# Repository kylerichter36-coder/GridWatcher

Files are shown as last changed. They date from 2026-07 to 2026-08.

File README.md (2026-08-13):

# GridWatcher






> **A ~R1,500 dual-device LoRa sensor + Raspberry Pi-class server system that predicts power outages before they happen, texts your phone, and retrains its own ML model automatically.**

---

## Why I Built This
Living with an unreliable local power grid meant sudden blackouts, lost work, and voltage sags damaging household electronics. Commercial utility monitors are either expensive proprietary hardware or reactive meters that only alert *after* the power is already out. GridWatcher was built to provide localized, real-time AC voltage and frequency telemetry with early-warning machine learning risk predictions and instant SMS notifications.

---

## System Architecture & Data Flow

```mermaid
graph LR
    subgraph Edge Hardware
        ZMPT[ZMPT101B AC Sensor] -->|ADC / GPIO2| ESP32[ESP32-C6 Base Station]
        ESP32 -->|Layer 1 C++ Rules| L1[Instant State: Normal/Sag/Surge/Blackout]
        ESP32 -->|Layer 2 C++ ML Engine| L2[Predictive Risk Score 0-100%]
    end

    subgraph Long-Range Telemetry
        ESP32 -->|12-Byte LoRa Packet| Handheld[ESP32-C6 Handheld Dashboard]
        ESP32 -->|12-Byte LoRa Packet| Pi[Orange Pi / Armbian Server]
    end

    subgraph Home Automation & ML Pipeline
        Pi -->|MQTT| HA[Home Assistant Dashboard]
        Pi -->|CSV Logger| Trainer[Windows Retraining GUI]
        Trainer -->|Train Random Forest| Header[Export C++ grid_model.h]
        Trainer -->|Auto-OTA Binaries| ESP32
        Pi -->|Termux ADB Bridge| SMS[Instant SMS Alerts]
    end
```

---

## System Categorization

### Implemented in V1
* **True RMS AC Sampling**: ZMPT101B RMS voltage sampling and zero-crossing frequency detection on GPIO 2.
* **Layer 1 State Machine**: Real-time deterministic C++ grid state classification (`BLACKOUT`, `SURGE`, `BROWNOUT_SAG`, `FREQ_JITTER`, `NORMAL`).
* **12-Byte Binary LoRa Protocol**: Compact binary packet structure (`GridPacket`) with magic header verification (`0x4757`).
* **Handheld TFT Dashboard**: ESP32-C6 handheld receiver with ST7789 240x135 display rendering live electrical, battery, and signal status.
* **Android Termux Gateway & SMS Bridge**: Refurbished Android phone running Termux/ADB to log cellular tower telemetry, host live status web endpoints, and dispatch instant SMS outage alerts via `termux-sms-send`.
* **Home Assistant Integration**: Real-time MQTT telemetry reporting and Lovelace dashboard integration.
* **1-Click Windows Setup**: Standalone `install_startup.bat` script that configures `arduino-cli`, ESP32 cores, and required libraries.

### Experimental Features (V1)
* **Layer 2 ML Risk Engine**: Random Forest ensemble (`grid_model.h`) evaluating 8 model inputs to compute continuous 0–30s pre-outage risk scores.
* **Pure Timestamp Feature Extraction**: Pure timestamp-based search (`timestamp_ms`) computing 10s and 30s rolling rates of change and variance.
* **Dual-Stage Wireless Auto-OTA**: Wi-Fi self-flashing engine checking local server (`192.168.3.47:5000`) with direct GitHub HTTPS fallback.

### Planned for V2 (Future Revision)
* **Custom Integrated PCB**: Monolithic PCB design replacing devboards and point-to-point wiring.
* **Precision AC Front-End**: Dedicated high-voltage metering IC with factory calibration against laboratory reference meters.
* **Feature Importance & Model Interpretability**: Extract and log Gini feature importance (and SHAP values) from the trained Random Forest to confirm whether `cell_signal` contributes meaningfully or is redundant relative to AC-derived features.
* **Cryptographic Packet Security**: Hardware-accelerated AES-128 payload encryption and packet signing.
* **Dedicated Hardware Watchdog**: External timer IC for emergency hardware reset during power dips.

---

<details>
<summary><b>Click to expand Deep Technical Specifications & Architecture</b></summary>

### Repository Structure

```
GridWatcher/
├── home_sender/              # ESP32-C6 Base Station transmitter firmware
│   ├── home_sender.ino       # ZMPT101B RMS sampling, Layer 1 status, 12-byte LoRa TX
│   └── grid_model.h          # Exported C++ Random Forest decision tree model
├── gridwatcher_dashboard2/   # ESP32 Handheld receiver & TFT dashboard firmware
│   └── gridwatcher_dashboard2.ino
├── windows_trainer/          # Automated Windows training pipeline & GUI
│   ├── gridwatcher_ml_gui.py # PyQt GUI, gap-aware feature extractor, C++ exporter
│   └── install_startup.bat   # 1-click dependency installer (arduino-cli standalone)
├── WORKING_ON/               # Active development status & phase documentation
│   └── README.md
└── version.json              # Current firmware & ML model version manifest
```

### Prototype Bill of Materials & Cost Breakdown (ZAR)

| Unit | Key Components | Prototype Cost (incl 15% VAT) |
|---|---|:---:|
| **Handheld Receiver Dashboard** | ESP32-C6, SX1262 LoRa, ST7789 TFT Display, 2000mAh LiPo, 868MHz High-Gain Antenna, Protoboard | **R736** |
| **Base Station Sender** | ESP32-C6, SX1262 LoRa, ZMPT101B AC Sensor, Hi-Link 5V Power, Boost Regulator, 868MHz High-Gain Antenna, LiPo Backup | **R843** |
| **Central Home Server & Gateway** | Armbian/Orange Pi Server + Refurbished Android Phone (Termux) | Reused / R0 |
| **Total Combined Prototype Build** | Both complete units including antennas, cabling, and hardware | **~R1,580** |

### Core Technical Design

#### Design Philosophy
GridWatcher combines direct AC power delivery measurements with auxiliary environmental side-channel indicators to predict electrical grid instability.

#### 1. Dual-Layer Classification Architecture

* **Layer 1: Deterministic C++ State Machine (`home_sender.ino`)**
  Evaluates instantaneous voltage and frequency using strict severity precedence:
  1. **Blackout**: `V < 180.0V` or `F < 45.00Hz`
  2. **Voltage Surge**: `V > 250.0V`
  3. **Brownout Sag**: `180.0V <= V < 210.0V`
  4. **Frequency Jitter**: `210.0V <= V <= 250.0V` and (`F < 49.50Hz` or `F > 50.50Hz`)
  5. **Normal**: `210.0V <= V <= 250.0V` and `49.50Hz <= F <= 50.50Hz`

* **Layer 2: Experimental Time-Series ML Risk Model (`grid_model.h`)**
  Evaluates **8 total inputs** to compute continuous 0–30s pre-outage risk scores:

  ##### Feature Rationale & Engineering Hypotheses

  | Feature | Category | Rationale & Mechanics |
  |---|---|---|
  | `voltage` | Direct AC | Instantaneous RMS AC voltage (V); physically tracks supply level. |
  | `frequency` | Direct AC | Instantaneous line frequency (Hz); reflects utility generation/load balance. |
  | `dV_dt_10s` | Direct AC | 10-second voltage rate of change ($\text{V}/\text{s}$); detects rapid dips or surges. |
  | `dF_dt_10s` | Direct AC | 10-second frequency rate of change ($\text{Hz}/\text{s}$); catches sudden frequency decay. |
  | `v_std_30s` | Direct AC | 30-second voltage standard deviation; quantifies short-term AC amplitude instability. |
  | `f_std_30s` | Direct AC | 30-second frequency standard deviation; measures line frequency turbulence. |
  | `v_slope_30s` | Direct AC | 30-second linear regression voltage slope ($\text{V}/\text{s}$); captures multi-second voltage trend directional drift. |
  | `cell_signal` | Environmental | Cellular network tower signal strength (RSRP in dBm, clamped to -120 to 0 dBm). |

  * **Cellular RSRP Feature Rationale**:
    > **Engineering Hypothesis**: Cell towers sharing the regional utility feeder may show supply degradation or backup-power failover during severe grid stress, providing a secondary spatial/regional indicator alongside direct AC metrics. Expected to be a lagging signal (tower backup typically buffers 4–8 hours) rather than instantaneous, unlike the AC-derived features.

  Outputs an experimental risk score from 0.0% to 100.0% using an ensemble of 3 Random Forest decision trees (`max_depth=4`) exported directly into native C++ functions (`tree0()`, `tree1()`, `tree2()`).

#### 2. 12-Byte Binary LoRa Telemetry Protocol

Telemetry is packed into a 12-byte binary structure (`GridPacket`), providing an **approximately 2.8x reduction in payload data size** compared to the legacy 34-byte ASCII string payload ($34 / 12 \approx 2.83\times$):

```cpp
struct __attribute__((packed)) GridPacket {
    uint16_t magic = 0x4757;  // 2 Bytes: 'GW' Sync Header
    int16_t  voltage_x10;     // 2 Bytes: Scaled Voltage (e.g. 2301 = 230.1V)
    uint16_t freq_x100;       // 2 Bytes: Scaled Frequency (e.g. 5000 = 50.00Hz)
    uint8_t  status;          // 1 Byte: GridStatus Enum (0..4)
    uint8_t  risk_score;      // 1 Byte: Experimental Risk % (0..100)
    uint8_t  ml_version;      // 1 Byte: Model Version (ML_MODEL_VERSION)
    int8_t   rssi;            // 1 Byte: Cellular Tower Signal Strength RSRP (-120..0 dBm)
    uint8_t  base_battery;    // 1 Byte: Base Station Battery % (0..100)
    int8_t   phone_battery;   // 1 Byte: Phone Hotspot Battery % (-1 or 0..100)
};
// Total Size: 12 Bytes
```

Both Handheld and Server receivers validate `packet.magic == 0x4757` to verify packet structure and reject malformed or unrelated RF data.

### Machine Learning Pipeline & Training

1. Telemetry datasets are logged automatically by the Orange Pi server (~10s log interval).
2. `gridwatcher_ml_gui.py` loads `telemetry.csv` and computes rolling features with timestamp gap invalidation ($\Delta t > 35.0\text{s}$).
3. Samples are labeled with a continuous 0–30s forward-looking horizon (`target_risk = 1` if an anomaly occurs within the upcoming 30 seconds while current state is Normal).
4. Scikit-Learn performs a **chronological 80/20 train/test holdout split** on historical telemetry, fitting a 3-tree Random Forest classifier (**86.48% training accuracy / 82.75% test holdout accuracy** for live model **v31**) and exporting decision rules into `home_sender/grid_model.h`. *Note: Accuracy is an experimental metric evaluated on historical local dataset logs and does not serve as a guarantee of real-world outage prediction capability.*
5. The Base Station firmware is compiled using `arduino-cli` and updated wirelessly via local HTTP OTA or direct GitHub HTTPS fallback.

### Current Prototype Limitations

1. **Prototype Hardware Measurement**: The ZMPT101B analog sensing module and ESP32 ADC chain are prototype-grade components and have not been calibrated against laboratory-grade reference meters.
2. **Experimental ML Validation**: The machine learning model is trained on telemetry from a single installation site. Real-world outage prediction accuracy requires extensive multi-site dataset validation across diverse grid topologies.
3. **OTA Network Scope & Security**: While local network OTA endpoints (`/update`, `/trigger-ota`) operate unauthenticated within a trusted LAN boundary, the direct GitHub fallback path fetches firmware binaries over the public internet using `setInsecure()` TLS without certificate pin verification.
4. **Known Limitations of the Cellular RSRP Feature**:
   * **Single-Tower Dependency**: Telemetry currently observes a single cell tower's backup behavior rather than a true regional signal until multiple gateway locations are logging.
   * **Site & Carrier Variation**: Tower backup behavior varies significantly by carrier and site (battery-only vs. generator-backed), causing RSRP proxy reliability to be inconsistent across network sectors.
   * **Feature Importance Unvalidated**: RSRP has not yet been quantitatively validated against Gini/SHAP feature importance metrics to confirm whether the trained model actively relies on this feature during real anomaly events vs. riding along with AC voltage features.

</details>

---

## Local Setup & Installation

Sensitive credentials are excluded from source control via `.gitignore`:
* **Wi-Fi Credentials**: Loaded via `home_sender/secrets.h` (`#if __has_include("secrets.h")`) or hardware NVS storage.
* **AP & OTA Passwords**: Defined as configurable macros (`#ifndef AP_PASSWORD`, `#ifndef OTA_PASSWORD`) overridable via `secrets.h`.
* **Server Credentials**: `gridwatcher_ml_gui.py` checks environment variable `GRIDWATCHER_PI_PASS` or local `secrets.json` before falling back to dev defaults.

To set up a new machine:
1. Run `windows_trainer/install_startup.bat` to install `arduino-cli`, the ESP32 board core, required libraries (`RadioLib`, `Adafruit GFX`, `ST7789`, `BusIO`), and Python dependencies.
2. Launch `windows_trainer/gridwatcher_ml_gui.py` to run retraining and automated OTA deployment.

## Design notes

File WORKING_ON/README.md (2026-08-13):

# Active Development & Work In Progress

This directory tracks active development status, system verification, and the engineering roadmap for the GridWatcher project.

---

## Current Status: GridWatcher V1 (Functional Prototype)

### Completed V1 Accomplishments

1. **Dual-Layer Anomaly & Predictive Risk Engine**
   - **Layer 1 (Deterministic Rules)**: Implemented C++ threshold state machine in `home_sender.ino` (`BLACKOUT`, `SURGE`, `BROWNOUT_SAG`, `FREQ_JITTER`, `NORMAL`) using strict evaluation precedence.
   - **Layer 2 (Experimental ML Risk Model)**: Implemented Random Forest model (`grid_model.h`) operating on 8 total inputs (voltage, frequency, cell signal, `dV/dt_10s`, `dF_dt_10s`, `v_std_30s`, `f_std_30s`, `v_slope_30s`).
   - **Pure Timestamp Search**: Implemented pure timestamp-based search (`timestamp_ms`) in `computeRollingFeatures()` for 10s and 30s rate of change and regression slope.

2. **12-Byte Binary LoRa Protocol Migration**
   - Migrated from legacy ASCII string transmission (`V:230.1,F:50.0...`) to a 12-byte binary packed struct (`GridPacket`).
   - Achieved an **approximately 2.8x reduction in payload data size** ($34 / 12 \approx 2.83\times$, ~8ms transmission duration), complying with EU868 and US915 duty-cycle budgets.
   - Validates `0x4757` magic sync header in receiver firmware to verify packet structure and reject malformed/unrelated RF data.

3. **Machine Learning Pipeline & Evaluation**
   - Implemented continuous 0–30s forward-looking target labeling in `gridwatcher_ml_gui.py` for early-warning outage risk classification.
   - Chronological 80/20 train/test holdout split evaluating **86.48% Train Accuracy / 82.75% Test Holdout Accuracy** (`v31`).
   - Automated Scikit-Learn tree export directly into C++ conditional logic (`tree0`, `tree1`, `tree2`).

4. **Multi-Machine Deployment & Security Refinements**
   - Configurable AP/OTA passwords (`AP_PASSWORD`, `OTA_PASSWORD`) and environment/json server credentials (`GRIDWATCHER_PI_PASS` / `secrets.json`).
   - Android Termux cellular gateway and SMS bridge (`phone_server/live_cell_bridge.py`) capturing cell tower RSRP telemetry and sending instant SMS alerts via `termux-sms-send`.
   - Updated `install_startup.bat` to automatically download standalone `arduino-cli` and required Arduino libraries (`RadioLib`, `Adafruit GFX`, `Adafruit ST7789`, `Adafruit BusIO`).
   - Direct dual-stage Auto-OTA engine checking local server (`192.168.3.47:5000`) with direct GitHub HTTPS fallback.

---

## Task Verification & Component Matrix

| Component | Status | Verification Summary |
|---|---|---|
| `home_sender.ino` | Completed | Pure timestamp-based search, 30-sample ring buffer, Layer 1 state machine, Layer 2 RF integration, 12-byte binary LoRa TX. |
| `grid_model.h` | Completed | 3-tree Random Forest C++ export with 8 model inputs (`v31`). |
| `gridwatcher_dashboard2.ino` | Completed | Binary struct unpacking (12 bytes), configurable OTA password, and magic header `0x4757` verification. |
| `gridwatcher_ml_gui.py` | Completed | Gap-aware feature extraction ($\Delta t > 35s$), chronological 80/20 train/test holdout evaluation, 1-click single-binary OTA pipeline. |
| `install_startup.bat` | Completed | Standalone `arduino-cli` download, ESP32 core install, library dependency resolution. |

---

## Roadmap: Planned for V2 (Custom PCB Revision)

* **Monolithic PCB Hardware**: Replace prototype breadboard wiring with a custom 2-layer PCB.
* **Calibrated High-Voltage AC Metering**: Integrate dedicated metering IC (e.g. ADE7753 / ATM90E26) calibrated against laboratory-grade reference meters.
* **Cryptographic Security**: Hardware AES-128 payload encryption and HMAC packet signing.
* **Enclosure & Power Supply**: Custom 3D-printed DIN-rail enclosure with integrated UPS battery backup.

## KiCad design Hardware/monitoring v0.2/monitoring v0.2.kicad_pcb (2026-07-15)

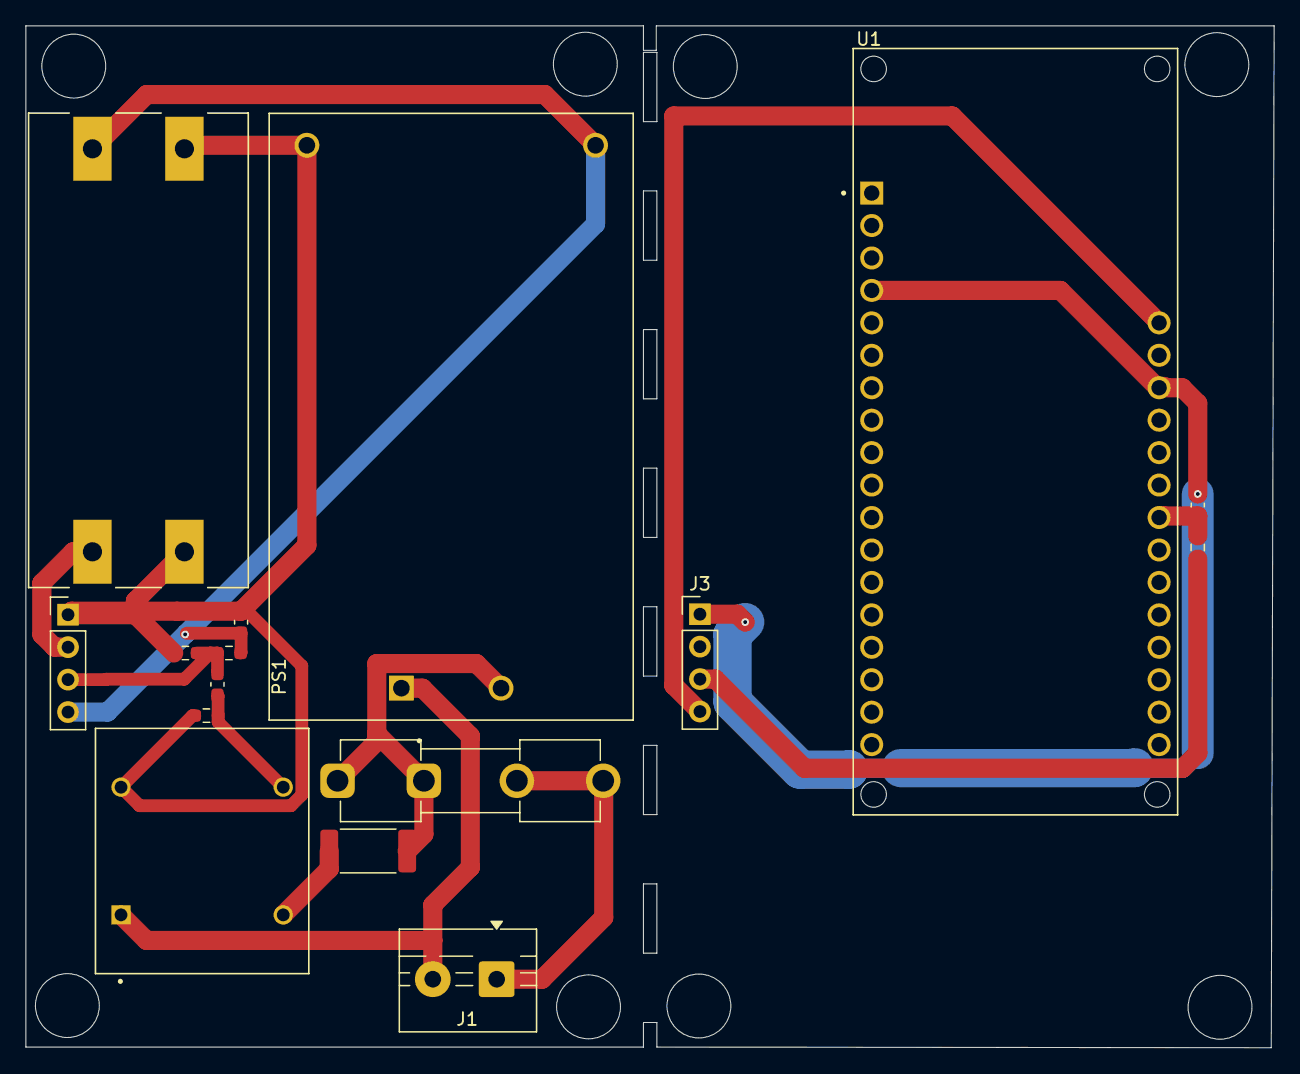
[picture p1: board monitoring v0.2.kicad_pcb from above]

Board: 2 copper layers, 97.7 x 80.0 mm, 16 parts (0 on the bottom side), 11 nets.

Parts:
C1: 1uF; C_0603_1608Metric_Pad1.08x0.95mm_HandSolder
C2: 0.1uF; C_0603_1608Metric_Pad1.08x0.95mm_HandSolder
C3: 10nF; C_0603_1608Metric_Pad1.08x0.95mm_HandSolder
F1: 1A; Fuseholder_Clip-5x20mm_Eaton_1A5601-01_Inline_P20.80x6.76mm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
J1: ST01x02; TerminalBlock_MaiXu_MX126-5.0-02P_1x02_P5.00mm
J2, J3: Conn_01x04_Pin; PinHeader_1x04_P2.54mm_Vertical
PS1: HLK-10M05; CONV_HLK-10M05
R1: 820K; R_2512_6332Metric_Pad1.40x3.35mm_HandSolder
R2: |2k; R_0603_1608Metric_Pad0.98x0.95mm_HandSolder
R3: 10k; R_0603_1608Metric_Pad0.98x0.95mm_HandSolder
R4: 5.1K; R_0603_1608Metric_Pad0.98x0.95mm_HandSolder
R5: 100; R_0603_1608Metric_Pad0.98x0.95mm_HandSolder
T1: ZMPT101B; XFMR_ZMPT101B
U1: DFR0654; MODULE_DFR0654
U2: MT3608_DC-DC_STEP_UP_CONVERTER_2A_BOOSTER_MODULE; MODULE_MT3608_DC-DC_STEP_UP_CONVERTER_2A_BOOSTER_MODULE

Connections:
3.3V: U1.2 (3.3V), U1.31 (3.3V)
/2v-28v: J2.2, U2.VOUT_P (VOUT+)
/5v: C2.2, J2.4, J3.4, PS1.4 (+VO), R3.2, U1.32 (VCC), U2.VIN_P (VIN+)
/L: F1.2, J1.1
/N: J1.2, PS1.1 (AC1), T1.1
/ZMPT101B: C1.2, J2.3, J3.3, R3.1, R4.2, R5.2
GND: C2.1, C3.2, J2.1, J3.1, PS1.3 (-VO), R2.1, R4.1, T1.4, U1.4 (GND), U1.30 (GND), U2.VIN_N (VIN-), U2.VOUT_N (VOUT-)
unnamed: C1.1, R2.2, T1.3
unnamed: F1.1, PS1.2 (AC2), R1.1
unnamed: R1.2, T1.2
unnamed: C3.1, R5.1, U1.26 (A3)

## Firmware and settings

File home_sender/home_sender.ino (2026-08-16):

/*
  GridWatcher: Base Station (Transmitter) — v3 Legal + Optimized
  Hardware: FireBeetle 2 ESP32-C6, SX1262 LoRa, MT3608 Step-up

  Compliance & Fixes:
  - TX interval 2000ms (was 1000ms) — EU/SA 868MHz 1% duty cycle compliance
  - TX power reduced to +14dBm (was +22dBm) — lowers battery draw & stays legal
  - Cell signal staleness timeout: 30s before marking as -999
  - Reinit backoff: doubles wait time on each failed reinit (max 80s)
  - Boot delay reduced to 500ms
  - Serial verbose mode flag (set false to suppress per-packet spam)
  - Battery: 5-sample average for stable reading
  - snprintf payloads — zero heap allocation

  LoRa Packet Format:
  V:<voltage>,F:<freq>,B:<base_batt>,S:<cell_dbm>,PB:<phone_batt>,SEQ:<seq>
*/

#include <Arduino.h>
#include <SPI.h>
#include <WiFi.h>
#include <WiFiClientSecure.h>
#include <HTTPClient.h>
#include <WebServer.h>
#include <Update.h>
#include <ESPmDNS.h>
#include <LittleFS.h>
#include <RadioLib.h>
#include <Preferences.h>
#include "grid_model.h"

#define CURRENT_VERSION ML_MODEL_VERSION
const char* OTA_VERSION_URL      = "http://192.168.3.47:5000/api/firmware/version.json";
const char* OTA_BIN_URL          = "http://192.168.3.47:5000/api/firmware/home_sender.bin";
const char* OTA_HANDHELD_BIN_URL = "http://192.168.3.47:5000/api/firmware/handheld.bin";

#ifndef LED_BUILTIN
  #define LED_BUILTIN 8
#endif
#define LED_PIN LED_BUILTIN

bool handheldUpdateReady = false;   // handheld.bin uploaded and waiting

void blinkDebugLED(int count) {
  for (int i = 0; i < count; i++) {
    digitalWrite(LED_PIN, HIGH);
    delay(100);
    digitalWrite(LED_PIN, LOW);
    delay(100);
  }
}

// GitHub Direct HTTP/HTTPS Auto-OTA Self-Flashing Engine (Local Server + GitHub Fallback)
void checkGitHubAutoOTA() {
  if (WiFi.status() != WL_CONNECTED) return;
  Serial.printf("[Auto-OTA] Checking for firmware updates (Local Version: v%d)...\n", CURRENT_VERSION);
  
  int remoteVersion = 0;
  String binUrl = "";
  String handheldUrl = "";

  // 1. Try Orange Pi local server first
  WiFiClient client;
  HTTPClient http;
  if (http.begin(client, OTA_VERSION_URL)) {
    int httpCode = http.GET();
    if (httpCode == HTTP_CODE_OK) {
      String payload = http.getString();
      int idx = payload.indexOf("\"version\":");
      if (idx != -1) {
        remoteVersion = payload.substring(idx + 10).toInt();
        binUrl = OTA_BIN_URL;
        handheldUrl = OTA_HANDHELD_BIN_URL;
      }
    }
    http.end();
  }

  // 2. Fall back to GitHub HTTPS if local server is unreachable
  if (remoteVersion == 0) {
    WiFiClientSecure secureClient;
    secureClient.setInsecure(); // Direct raw HTTPS fetch without root cert chain check
    if (http.begin(secureClient, "https://raw.githubusercontent.com/kylerichter36-coder/GridWatcher/main/version.json")) {
      int httpCode = http.GET();
      if (httpCode == HTTP_CODE_OK) {
        String payload = http.getString();
        int idx = payload.indexOf("\"version\":");
        if (idx != -1) {
          remoteVersion = payload.substring(idx + 10).toInt();
          binUrl = "https://raw.githubusercontent.com/kylerichter36-coder/GridWatcher/main/home_sender.bin";
          handheldUrl = "https://raw.githubusercontent.com/kylerichter36-coder/GridWatcher/main/handheld.bin";
        }
      }
      http.end();
    }
  }

  if (remoteVersion == 0) {
    Serial.println("[Auto-OTA] Could not check remote version from local server or GitHub.");
    return;
  }

  Serial.printf("[Auto-OTA] Version Check -> Local: v%d | Remote: v%d\n", CURRENT_VERSION, remoteVersion);

  if (remoteVersion <= CURRENT_VERSION) {
    Serial.printf("[Auto-OTA] Device is up to date (v%d >= v%d). No update required.\n", CURRENT_VERSION, remoteVersion);
    return;
  }

  // 3. Remote version is newer — download and flash home_sender.bin
  Serial.printf("[Auto-OTA] NEW FIRMWARE AVAILABLE! Upgrading v%d -> v%d...\n", CURRENT_VERSION, remoteVersion);
  Serial.printf("[Auto-OTA] Downloading binary from %s...\n", binUrl.c_str());

  bool isHttps = binUrl.startsWith("https");
  HTTPClient otaHttp;
  int httpCode = -1;

  if (isHttps) {
    WiFiClientSecure secClient;
    secClient.setInsecure();
    if (otaHttp.begin(secClient, binUrl)) {
      httpCode = otaHttp.GET();
    }
  } else {
    WiFiClient netClient;
    if (otaHttp.begin(netClient, binUrl)) {
      httpCode = otaHttp.GET();
    }
  }

  if (httpCode != HTTP_CODE_OK) {
    Serial.printf("[Auto-OTA] ERROR: Failed to download firmware binary (HTTP Code: %d). Aborting update.\n", httpCode);
    otaHttp.end();
    return;
  }

  int contentLength = otaHttp.getSize();
  if (contentLength < 100000) {
    Serial.printf("[Auto-OTA] ERROR: Firmware binary too small or invalid size (%d bytes). Aborting update.\n", contentLength);
    otaHttp.end();
    return;
  }

  Serial.printf("[Auto-OTA] Binary size: %d bytes. Flashing OTA update partition...\n", contentLength);

  if (!Update.begin(contentLength)) {
    Serial.printf("[Auto-OTA] ERROR: Update.begin(%d) failed! Code: ", contentLength);
    Update.printError(Serial);
    otaHttp.end();
    return;
  }

  WiFiClient* stream = otaHttp.getStreamPtr();
  size_t written = Update.writeStream(*stream);
  otaHttp.end();

  if (written != (size_t)contentLength) {
    Serial.printf("[Auto-OTA] ERROR: Wrote %d / %d bytes. Update incomplete!\n", (int)written, contentLength);
    Update.end(false);
    return;
  }

  if (!Update.end(true)) {
    Serial.print("[Auto-OTA] ERROR: Update.end() failed: ");
    Update.printError(Serial);
    return;
  }

  if (Update.hasError()) {
    Serial.print("[Auto-OTA] ERROR: Flashing encountered errors: ");
    Update.printError(Serial);
    return;
  }

  Serial.printf("[Auto-OTA] SUCCESS: Firmware v%d successfully flashed! Rebooting in 1s...\n", remoteVersion);
  delay(1000);
  ESP.restart();
}

// ==============================================================================
// [0] CONFIG FLAGS
// ==============================================================================
#define SERIAL_VERBOSE    true    // Set false to suppress per-packet TX log spam
#define TX_INTERVAL_MS    2000
#define TX_POWER_DBM      9    // +5 dBi antenna: 9dBm TX + 5dBi - 1dB loss = ~13dBm EIRP = ~12mW ERP
                               // Legal limit is 25mW ERP. Change to 22 ONLY if using a simple wire/0dBi antenna.
#define CELL_STALE_MS     30000

// LoRa radio config — MUST match exactly on sender and handheld
#define LORA_FREQ     868.0
#define LORA_BW       125.0
#define LORA_SF       10
#define LORA_CR       7
#define LORA_SYNC     0x12
#define LORA_PREAMBLE 8

// OTA Hub state — tracks which devices still need to update
bool bridgeUpdateReady    = false;   // bridge.py uploaded and waiting
bool senderUpdatePending  = false;   // sender own firmware staged, waiting for others
bool handheldConfirmed    = false;   // handheld reported OK
bool bridgeConfirmed      = false;   // phone bridge reported OK

// Grid State
float lastVoltage         = 0.0;
float lastFrequency       = 0.0;
float zmptCalibration     = 0.46;  // Multiplier mapping raw RMS ADC units to real AC Volts (adjust via /calibrate?val=0.46)
#define PIN_BOOT_BTN      9
#define PIN_ZMPT          6        // ZMPT101B active module analog OUT on GPIO 6

// Sender hub dashboard — upload firmware for all 3 devices from one page.
// Laptop accesses this at http://gridwatcher-sender.local/ota (stays on home WiFi).
const char HUB_HTML[] PROGMEM = R"rawliteral(
<!DOCTYPE html><html><head><meta charset='UTF-8'>
<title>GridWatcher OTA Hub</title>
<meta http-equiv='refresh' content='5'>
<style>
body{font-family:sans-serif;background:#0d1117;color:#e6edf3;margin:0;padding:20px;}
h1{color:#58a6ff;border-bottom:1px solid #30363d;padding-bottom:10px;}
.card{background:#161b22;border:1px solid #30363d;border-radius:8px;padding:16px;margin:12px 0;}
.card h3{margin-top:0;color:#79c0ff;}
.status{display:inline-block;padding:3px 10px;border-radius:12px;font-size:0.85em;font-weight:bold;}
.ok{background:#1a4731;color:#3fb950;}
.wait{background:#3d2b00;color:#e3b341;}
.ready{background:#1f3d6e;color:#58a6ff;}
input[type=file]{background:#21262d;color:#e6edf3;border:1px solid #30363d;padding:6px;border-radius:4px;width:100%;margin:8px 0;}
btn,input[type=submit]{padding:8px 16px;background:#238636;color:#fff;border:none;border-radius:6px;cursor:pointer;font-weight:bold;margin-top:6px;}
btn:hover,input[type=submit]:hover{background:#2ea043;}
.info{color:#8b949e;font-size:0.85em;margin-top:4px;}
table{width:100%;border-collapse:collapse;}
td,th{padding:8px 12px;border:1px solid #30363d;text-align:left;}
th{background:#21262d;color:#79c0ff;}
</style></head><body>
<h1>GridWatcher OTA Hub</h1>
<div class='card'>
<h3>Device Status</h3>
<table><tr><th>Device</th><th>Update Ready</th><th>Confirmed</th></tr>
<tr><td>Handheld</td>
    <td><span class='status %HREADY%'>%HREADYTXT%</span></td>
    <td><span class='status %HCONF%'>%HCONFTXT%</span></td></tr>
<tr><td>Phone Bridge</td>
    <td><span class='status %BREADY%'>%BREADYTXT%</span></td>
    <td><span class='status %BCONF%'>%BCONFTXT%</span></td></tr>
<tr><td>Sender (self)</td>
    <td><span class='status %SREADY%'>%SREADYTXT%</span></td>
    <td><span class='status ok'>%SCONFTXT%</span></td></tr>
</table>
</div>
<div class='card'>
<h3>1. Upload Handheld Firmware</h3>
<p class='info'>handheld will pull this automatically when you hold BOOT for 3s</p>
<form method='POST' action='/upload-handheld' enctype='multipart/form-data'>
<input type='file' name='file' accept='.bin'>
<input type='submit' value='Upload Handheld Firmware'>
</form>
</div>
<div class='card'>
<h3>2. Upload Bridge Script</h3>
<p class='info'>phone bridge checks for this on every startup</p>
<form method='POST' action='/upload-bridge' enctype='multipart/form-data'>
<input type='file' name='file' accept='.py'>
<input type='submit' value='Upload Bridge Script'>
</form>
</div>
<div class='card'>
<h3>3. Upload Sender Firmware (applied last)</h3>
<p class='info'>sender stages this and reboots automatically after handheld + phone confirm</p>
<form method='POST' action='/update' enctype='multipart/form-data'>
<input type='file' name='update' accept='.bin'>
<input type='submit' value='Stage Sender Firmware'>
</form>
</div>
</body></html>)rawliteral";

// ==============================================================================
// [1] HARDWARE & PIN DEFINITIONS
// ==============================================================================
#define LORA_CS   14
#define LORA_DIO1 4
#define LORA_RST  1
#define LORA_BUSY 5
#define PIN_BAT   0

// Onboard LED for visual TX feedback (no terminal needed)
// FireBeetle 2 ESP32-C6: try LED_BUILTIN first; change to your board's LED pin if needed
#ifndef LED_BUILTIN
  #define LED_BUILTIN 8
#endif
#define LED_PIN LED_BUILTIN
#define LED_TX_MS   30    // Short blip on successful TX
#define LED_ERR_MS  120   // Longer pulse on TX fail
unsigned long ledOffMs = 0;  // millis() when LED should turn off (0 = already off)

// ==============================================================================
// secrets.h is only present on the home PC that originally flashed this device.
// On other PCs (e.g. for ML retraining), it won't exist — that is fine because
// the compiled binary gets OTA-flashed FROM the Orange Pi which has the correct
// binary already. The #if __has_include guard prevents compile errors.
#if __has_include("secrets.h")
  #include "secrets.h"
#endif

// ---- Home WiFi (primary) ----
#ifdef SECRET_WIFI_SSID
const char* homeSSID = SECRET_WIFI_SSID;
const char* homePass = SECRET_WIFI_PASS;
#else
// No secrets.h on this PC — credentials are already stored in NVS from original flash
const char* homeSSID = "";
const char* homePass = "";
#endif

// ---- Phone hotspot (fallback when away from home) ----
const char* phoneSSID = "YOUR_PHONE_HOTSPOT_NAME";     // <-- fill in
const char* phonePass = "YOUR_PHONE_HOTSPOT_PASSWORD"; // <-- fill in

// ---- Sender AP (always on, for local debugging) ----
#ifndef AP_PASSWORD
  #define AP_PASSWORD "gridwatcher123"
#endif
const char* apSSID   = "GridWatcher-AP";
const char* apPass   = AP_PASSWORD;

// mDNS hostname — access OTA at http://gridwatcher-sender.local/update from any
// device on the same network. No WiFi switching needed on laptop.
#define MDNS_HOSTNAME "gridwatcher-sender"

WebServer server(80);

// ==============================================================================
// [3] GLOBALS, PACKET STRUCT & FEATURE CALCULATOR
// ==============================================================================
struct __attribute__((packed)) GridPacket {
    uint16_t magic = 0x4757;  // 2 Bytes: 'GW' Sync Header
    int16_t  voltage_x10;     // 2 Bytes: e.g. 2301 = 230.1V
    uint16_t freq_x100;       // 2 Bytes: e.g. 5000 = 50.00Hz
    uint8_t  status;          // 1 Byte: GridStatus Enum (0..4)
    uint8_t  risk_score;      // 1 Byte: Predictive Risk % (0..100)
    uint8_t  ml_version;      // 1 Byte: Model Version
    int8_t   rssi;            // 1 Byte: Cell Signal dBm
    uint8_t  base_battery;    // 1 Byte: Base Station Battery % (0..100)
    int8_t   phone_battery;   // 1 Byte: Phone Hotspot Battery % (-1 or 0..100)
};

struct TelemetrySample {
    float voltage;
    float frequency;
    unsigned long timestamp_ms;
};

#define RING_BUF_SIZE 30
TelemetrySample ringBuf[RING_BUF_SIZE];
int ringHead = 0;
int sampleCount = 0;

void addTelemetrySample(float v, float f, unsigned long ts) {
    ringBuf[ringHead] = {v, f, ts};
    ringHead = (ringHead + 1) % RING_BUF_SIZE;
    if (sampleCount < RING_BUF_SIZE) sampleCount++;
}

bool isRingBufferWarmedUp() {
    if (sampleCount < 2) return false;
    int idxOldest = (ringHead - sampleCount + RING_BUF_SIZE) % RING_BUF_SIZE;
    int idxNow    = (ringHead - 1 + RING_BUF_SIZE) % RING_BUF_SIZE;
    unsigned long elapsed = ringBuf[idxNow].timestamp_ms - ringBuf[idxOldest].timestamp_ms;
    return (elapsed >= 25000); // Warmed up when at least 25-30 real seconds of continuous telemetry are in buffer
}

// Layer 1: Strict Evaluation Precedence State Machine
GridStatus classifyGridStatus(float voltage, float frequency) {
    // 1. BLACKOUT (Highest Severity)
    if (voltage < 180.0f || frequency < 45.00f) {
        return GRID_STATUS_BLACKOUT;
    }
    // 2. SURGE
    if (voltage > 250.0f) {
        return GRID_STATUS_SURGE;
    }
    // 3. BROWNOUT SAG
    if (voltage >= 180.0f && voltage < 210.0f) {
        return GRID_STATUS_BROWNOUT_SAG;
    }
    // 4. FREQUENCY JITTER (Voltage normal 210V-250V, but frequency outside 49.5-50.5Hz)
    if (voltage >= 210.0f && voltage <= 250.0f && (frequency < 49.50f || frequency > 50.50f)) {
        return GRID_STATUS_FREQ_JITTER;
    }
    // 5. NORMAL (Lowest Severity)
    return GRID_STATUS_NORMAL;
}

void computeRollingFeatures(float &dV_dt_10s, float &dF_dt_10s, float &v_std_30s, float &f_std_30s, float &v_slope_30s) {
    if (!isRingBufferWarmedUp()) {
        dV_dt_10s = 0.0f; dF_dt_10s = 0.0f; v_std_30s = 0.0f; f_std_30s = 0.0f; v_slope_30s = 0.0f;
        return;
    }

    int idxNow = (ringHead - 1 + RING_BUF_SIZE) % RING_BUF_SIZE;
    unsigned long nowTs = ringBuf[idxNow].timestamp_ms;

    // 1. Pure timestamp-based search for sample closest to 10 seconds ago (10,000 ms)
    int idx10s = idxNow;
    float bestDiff10s = 999999.0f;
    for (int i = 1; i < sampleCount; i++) {
        int idx = (ringHead - 1 - i + RING_BUF_SIZE) % RING_BUF_SIZE;
        unsigned long elapsedMs = nowTs - ringBuf[idx].timestamp_ms;
        float diff = abs((float)elapsedMs - 10000.0f);
        if (diff < bestDiff10s) {
            bestDiff10s = diff;
            idx10s = idx;
        }
        if (elapsedMs > 15000) break; // Don't search past 15s
    }

    float dt10 = (nowTs - ringBuf[idx10s].timestamp_ms) / 1000.0f;
    if (dt10 < 1.0f) dt10 = 10.0f; // Safety fallback

    dV_dt_10s = (ringBuf[idxNow].voltage - ringBuf[idx10s].voltage) / dt10;
    dF_dt_10s = (ringBuf[idxNow].frequency - ringBuf[idx10s].frequency) / dt10;

    // 2. Pure timestamp-based collection for samples within the last 30 seconds (30,000 ms)
    int samplesIn30s = 0;
    int indices30s[RING_BUF_SIZE];
    for (int i = 0; i < sampleCount; i++) {
        int idx = (ringHead - 1 - i + RING_BUF_SIZE) % RING_BUF_SIZE;
        unsigned long elapsedMs = nowTs - ringBuf[idx].timestamp_ms;
        if (elapsedMs <= 30000) {
            indices30s[samplesIn30s++] = idx;
        } else {
            break;
        }
    }

    if (samplesIn30s < 2) {
        v_std_30s = 0.0f; f_std_30s = 0.0f; v_slope_30s = 0.0f;
        return;
    }

    // Process from oldest to newest in the 30s window
    float vSum = 0.0f, fSum = 0.0f, tSum = 0.0f;
    float tVals[RING_BUF_SIZE];
    float vVals[RING_BUF_SIZE];
    float fVals[RING_BUF_SIZE];

    unsigned long t0 = ringBuf[indices30s[samplesIn30s - 1]].timestamp_ms;

    for (int i = 0; i < samplesIn30s; i++) {
        int idx = indices30s[samplesIn30s - 1 - i];
        float tSec = (ringBuf[idx].timestamp_ms - t0) / 1000.0f;
        tVals[i] = tSec;
        vVals[i] = ringBuf[idx].voltage;
        fVals[i] = ringBuf[idx].frequency;
        vSum += vVals[i];
        fSum += fVals[i];
        tSum += tSec;
    }

    float vMean = vSum / (float)samplesIn30s;
    float fMean = fSum / (float)samplesIn30s;
    float tMean = tSum / (float)samplesIn30s;

    float vSqDiff = 0.0f, fSqDiff = 0.0f;
    float num = 0.0f, den = 0.0f;

    for (int i = 0; i < samplesIn30s; i++) {
        float vDiff = vVals[i] - vMean;
        float fDiff = fVals[i] - fMean;
        float tDiff = tVals[i] - tMean;

        vSqDiff += vDiff * vDiff;
        fSqDiff += fDiff * fDiff;

        num += tDiff * vDiff;
        den += tDiff * tDiff;
    }

    v_std_30s = sqrt(vSqDiff / (float)samplesIn30s);
    f_std_30s = sqrt(fSqDiff / (float)samplesIn30s);
    v_slope_30s = (den > 0.0001f) ? (num / den) : 0.0f;
}

SX1262 radio = new Module(LORA_CS, LORA_DIO1, LORA_RST, LORA_BUSY);

int cellSignalDbm     = -999;
int phoneBatteryPercent = -1;
unsigned long lastCellUpdate = 0;
unsigned long lastSendTime   = 0;
unsigned long packetSequence = 0;
int batteryPercent = 100;
GridStatus lastGridStatus = GRID_STATUS_NORMAL;
uint8_t lastRiskScore = 0;
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
void loop() {
  server.handleClient();
  yield();
  ledTick(); // Non-blocking: turns LED off when its timer expires

  // Cell signal staleness check — expire stale data after CELL_STALE_MS
  if (lastCellUpdate > 0 && millis() - lastCellUpdate > CELL_STALE_MS) {
    if (cellSignalDbm != -999) {
      Serial.println("[WiFi] Cell signal data stale (>30s). Marking as unknown.");
      cellSignalDbm = -999;
    }
  }

    // 1Hz Telemetry Sampling Ticker (independent of 2s LoRa TX interval)
    // Ensures ring buffer receives 1 sample per second so 10 samples = 10s and 30 samples = 30s
    static unsigned long lastSampleTime = 0;
    if (millis() - lastSampleTime >= 1000) {
      lastSampleTime = millis();
      float realV = 0.0, realF = 0.0;
      readZMPT101B(realV, realF);
      lastVoltage = realV;
      lastFrequency = realF;
      addTelemetrySample(realV, realF, millis());
    }

    // Automatic telemetry broadcast every TX_INTERVAL_MS (2 seconds)
    if (millis() - lastSendTime >= TX_INTERVAL_MS) {
      lastSendTime = millis();
      packetSequence++;
      readBattery();

      // Layer 1: Deterministic state machine
      lastGridStatus = classifyGridStatus(lastVoltage, lastFrequency);

      // Layer 2: Time-series predictive risk model
      float dV_dt_10s = 0.0f, dF_dt_10s = 0.0f, v_std_30s = 0.0f, f_std_30s = 0.0f, v_slope_30s = 0.0f;
      computeRollingFeatures(dV_dt_10s, dF_dt_10s, v_std_30s, f_std_30s, v_slope_30s);

      // Clean signal sentinel: map -999 or invalid signals to -120 dBm (prevents int8_t wrap to +25)
      float modelSignal = (cellSignalDbm < -120 || cellSignalDbm == -999) ? -110.0f : (float)cellSignalDbm;
      int8_t pktRssi    = (cellSignalDbm < -120 || cellSignalDbm == -999) ? -120 : (int8_t)constrain(cellSignalDbm, -120, 0);

      float rawRisk = 0.0f;
      if (isRingBufferWarmedUp()) {
          rawRisk = predictGridRisk(lastVoltage, lastFrequency, modelSignal, dV_dt_10s, dF_dt_10s, v_std_30s, f_std_30s, v_slope_30s);
      }
      lastRiskScore = (uint8_t)constrain((int)rawRisk, 0, 100);

      // Pack 12-byte GridPacket struct
      GridPacket pkt;
      pkt.magic = 0x4757;
      pkt.voltage_x10 = (int16_t)(lastVoltage * 10.0f);
      pkt.freq_x100 = (uint16_t)(lastFrequency * 100.0f);
      pkt.status = (uint8_t)lastGridStatus;
      pkt.risk_score = lastRiskScore;
      pkt.ml_version = (uint8_t)CURRENT_VERSION;
      pkt.rssi = pktRssi;
      pkt.base_battery = (uint8_t)constrain(batteryPercent, 0, 100);
      pkt.phone_battery = (int8_t)phoneBatteryPercent;

      if (SERIAL_VERBOSE) {
        Serial.printf("TX [%lu]: V=%.1f F=%.2f Status=%d Risk=%d%% WarmedUp=%s RSSI=%d\n",
                      packetSequence, lastVoltage, lastFrequency, (int)lastGridStatus, (int)lastRiskScore, isRingBufferWarmedUp() ? "YES" : "NO", (int)pktRssi);
      }

      int state = radio.transmit((uint8_t*)&pkt, sizeof(GridPacket));

      if (state == RADIOLIB_ERR_NONE) {
        if (SERIAL_VERBOSE) Serial.println("  -> OK (12-byte Binary Packet Sent)");
        lastSuccessfulTx   = millis();
        consecutiveTxFails = 0;
        reinitBackoffMs    = 10000;
        // Short LED blip — TX success
        digitalWrite(LED_PIN, HIGH);
        ledOffMs = millis() + LED_TX_MS;
      } else {
        Serial.printf("TX FAIL (Code: %d)\n", state);
        consecutiveTxFails++;
        // Longer LED pulse — TX error
        digitalWrite(LED_PIN, HIGH);
        ledOffMs = millis() + LED_ERR_MS;
      }
    }

  // Radio watchdog with exponential backoff reinit
  if (consecutiveTxFails >= MAX_TX_FAILS ||
      (lastSuccessfulTx > 0 && millis() - lastSuccessfulTx > reinitBackoffMs)) {
    reinitRadio();
  }
}

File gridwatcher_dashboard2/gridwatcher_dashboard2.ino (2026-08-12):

/*
  GRIDWATCHR Handheld Dashboard v3 — Legal + Optimized
  FireBeetle 2 ESP32-C6 + 76x284 long-strip ST7789 TFT (portrait)

  Fixes in v3:
  - IRAM_ATTR ISR (was ICACHE_RAM_ATTR — ESP8266 only, broken on RISC-V)
  - drawWallpaper() uses memcpy instead of 21,584 drawPixel() calls (10-50x faster)
  - WiFi/OTA is OFF by default — activate with long BOOT button press (saves ~80mA)
  - Battery read throttled to every 30 seconds (was every second)
  - SLEEP_MS reduced to 2 minutes (was 5)
  - LINK_TIMEOUT_MS increased to 5000ms (fewer false OFFLINE flashes)
  - Packet loss counters reset on link reconnect
  - linkQual uses weighted RSSI + SNR (was SNR-only)
  - SNR displayed in WIRELESS section
  - Cell signal not shown when stale (was shown forever)

  LoRa Packet Format (v2):
  V:<voltage>,F:<freq>,B:<base_batt>,S:<cell_dbm>,PB:<phone_batt>,SEQ:<seq>
*/

#include <SPI.h>
#include <Adafruit_GFX.h>
#include <Adafruit_ST7789.h>
#include <RadioLib.h>
#include <WiFi.h>
#include <Update.h>
#include <HTTPClient.h>
#include "wallpaper.h"

enum GridStatus : uint8_t {
    GRID_STATUS_NORMAL       = 0,
    GRID_STATUS_BLACKOUT     = 1,
    GRID_STATUS_BROWNOUT_SAG = 2,
    GRID_STATUS_SURGE        = 3,
    GRID_STATUS_FREQ_JITTER  = 4
};

struct __attribute__((packed)) GridPacket {
    uint16_t magic = 0x4757;  // 2 Bytes: 'GW' Sync Header
    int16_t  voltage_x10;     // 2 Bytes: e.g. 2301 = 230.1V
    uint16_t freq_x100;       // 2 Bytes: e.g. 5000 = 50.00Hz
    uint8_t  status;          // 1 Byte: GridStatus Enum (0..4)
    uint8_t  risk_score;      // 1 Byte: Predictive Risk % (0..100)
    uint8_t  ml_version;      // 1 Byte: Model Version
    int8_t   rssi;            // 1 Byte: Cell Signal dBm
    uint8_t  base_battery;    // 1 Byte: Base Station Battery % (0..100)
    int8_t   phone_battery;   // 1 Byte: Phone Hotspot Battery % (-1 or 0..100)
};

uint8_t currentGridStatus = 0;
uint8_t currentRiskScore = 0;

// WiFi OTA — connects to sender AP and pulls firmware from sender hub
const char* otaSSID = "GridWatcher-Home";  // sender AP
#ifndef OTA_PASSWORD
  #define OTA_PASSWORD "gridwatcher123"
#endif
const char* otaUser = "admin";
const char* otaPass = OTA_PASSWORD;
#define SENDER_HOST "http://192.168.4.1"
bool otaModeActive = false;

// ---------- Pins ----------
#define PIN_SCL   23
#define PIN_SDA   22
#define PIN_RES   2
#define PIN_DC    20
#define PIN_CS    19
#define PIN_BLK   18
#define PIN_BAT   0
#define PIN_BOOT_BTN 9

// ---------- LoRa Pins ----------
#define LORA_CS   14
#define LORA_DIO1 4
#define LORA_RST  1
#define LORA_BUSY 5

// LoRa radio config — MUST match exactly on sender and handheld
#define LORA_FREQ   868.0
#define LORA_BW     125.0
#define LORA_SF     10      // Spreading Factor (7-12). Higher = longer range, slower
#define LORA_CR     7       // Coding Rate (5-8)
#define LORA_SYNC   0x12    // Sync word — private network
#define LORA_PREAMBLE 8

// Onboard LED for visual RX feedback
#ifndef LED_BUILTIN
  #define LED_BUILTIN 8
#endif
#define LED_PIN    LED_BUILTIN
#define LED_RX_MS  50
#define LED_ERR_MS 200
unsigned long ledOffMs = 0;

Adafruit_ST7789 tft = Adafruit_ST7789(&SPI, PIN_CS, PIN_DC, PIN_RES);
SX1262 radio = new Module(LORA_CS, LORA_DIO1, LORA_RST, LORA_BUSY);

#define SCR_W 76
#define SCR_H 284
GFXcanvas16 canvas(SCR_W, SCR_H);

// ---------- Theme Palettes ----------
struct Theme {
  uint16_t text; uint16_t dim; uint16_t line; uint16_t accent; uint16_t white;
};
const Theme THEME_DARK  = { 0xCE79, 0x738E, 0x39C7, 0x4D3F, 0xFFFF };
const Theme THEME_LIGHT = { 0x2124, 0x4A69, 0x9CD3, 0x11B5, 0x0000 };

#define COL_GOOD 0x2E8B
#define COL_WARN 0xFD20
#define COL_CRIT 0xF800
#define ENABLE_THEME_TOGGLE 1

bool darkMode = true;
Theme cur = THEME_DARK;

// ---------- Live Data Variables ----------
float voltage   = 0.0;
float freq_Hz   = 0.0;
int   rssi_dBm  = 0;
float snr_dB    = 0.0;
int   linkQual  = 0;
float pktLoss   = 0.0;

// AI Prediction
int   aiRisk = 0;
const char* aiState = "WAIT";
int   mlVersion = 3;
char  mlBuildTime[20] = "21:17:15";

int batteryPercent     = 0;
int batteryMilliVolts  = 0;
bool isCharging        = false;
unsigned long lastBattRead = 0;
#define BATT_READ_MS  30000  // Read battery every 30s (was every second)
#define BATT_GOOD_PCT 60
#define BATT_WARN_PCT 30

int homeBatteryPercent  = -1;
int phoneBatteryPercent = -1;
int cellSignalDbm       = -999;

// Link freshness
unsigned long lastPacketMillis = 0;
bool linkAlive = false;
#define LINK_TIMEOUT_MS 5000  // 5s (was 3s) — fewer false OFFLINE flashes

// Screen sleep
bool screenAwake       = true;
unsigned long lastActivity = 0;
const unsigned long SLEEP_MS = 2UL * 60UL * 1000UL;  // 2 min (was 5 min)

// Button long-press for OTA mode
#define OTA_LONG_PRESS_MS 3000
unsigned long btnPressStart = 0;
bool btnHeld = false;

// Voltage history graph
#define HIST_LEN 40
float vHist[HIST_LEN];
int histIdx = 0;

// AI: rolling voltage/freq history for anomaly detection
#define AI_HIST_LEN 10
float aiVoltHist[AI_HIST_LEN];
float aiFreqHist[AI_HIST_LEN];
int aiHistIdx = 0;

// Stats ticker — runs every 1s independent of display
unsigned long lastUpdate = 0;
const unsigned long UPDATE_MS = 1000;
bool btnLastRaw = HIGH;
unsigned long btnLastChange = 0;
const unsigned long DEBOUNCE_MS = 40;

// Data-triggered display — draw 50ms AFTER new data arrives, not on a fixed clock
volatile bool newDataFlag = false;
unsigned long dataReceivedMs = 0;
#define DRAW_DELAY_MS 50

// LoRa tracking stats
unsigned long lastExpectedSeq       = 0;
int packetsReceivedThisSecond       = 0;
float rxRate                        = 0.0;
long totalLostPackets               = 0;
long totalExpectedPackets           = 0;

// RX Watchdog — if no packet (or no flag set) for this long, force re-arm
#define RX_WATCHDOG_MS 15000
unsigned long lastRxArmTime = 0;

// ---------- Interrupt-driven receive flag ----------
volatile bool receivedFlag = false;

// FIXED: IRAM_ATTR (not ICACHE_RAM_ATTR which is ESP8266-only)
// IRAM_ATTR ensures the ISR runs from fast internal RAM on ESP32-C6 RISC-V
IRAM_ATTR void onPacketReceived(void) {
  receivedFlag = true;
}
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

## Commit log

2026-07-15 Initial commit: Setup repo structure and README
    [monitoring v0.2-B_Cu.gbr, monitoring v0.2-B_Mask.gbr, monitoring v0.2-B_Paste.gbr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]
2026-08-03 Fix battery charging detection: add EMA smoothing filter and 10s trend hysteresis
    [gridwatcher_dashboard2.ino]
2026-08-03 Increase LoRa SX1262 TX power from +10 dBm to max +22 dBm
2026-08-03 Add live ADB-Netcat cellular bridge for instant signal delivery to ESP32
2026-08-03 Optimize ADB signal read with instant grep filter
2026-08-03 Simplify ML dataset to only timestamp, voltage, and frequency
2026-08-03 Complete UI redesign: 5 sections, phone battery, AI risk, no emojis, no duplicate graphs
    [gridwatcher_dashboard2.ino, home_sender.ino]
2026-08-03 Fix title bar overlap: move uptime to footer
    [gridwatcher_dashboard2.ino]
2026-08-03 Update README with v2 dashboard UI, phone battery, telemetry bridge docs
2026-08-03 Fix transmitter hang: snprintf, radio watchdog, disable STA auto-reconnect
    [home_sender.ino]
2026-08-04 Add Web OTA handlers to ESP32 sketches, ota_push.py helper script, and Wireless ADB to phone bridge
2026-08-04 v3: All fixes — legal duty cycle, IRAM_ATTR, memcpy wallpaper, WiFi off by default, throttled ADB, batch sdcard, staleness, backoff, SNR display, loss reset
    [gridwatcher_dashboard2.ino, home_sender.ino]
2026-08-04 Fix RX dead lock: SPI interrupt guard, RX watchdog 15s, hard radio reset on boot, revert readData to String
    [gridwatcher_dashboard2.ino]
2026-08-04 Display only updates 50ms after RX data; fix RadioLib interrupt guard; separate stats ticker from draw
    [gridwatcher_dashboard2.ino]
2026-08-04 Add non-blocking LED flash: sender blinks on TX, handheld blinks on RX, long pulse on errors/watchdog
    [gridwatcher_dashboard2.ino, home_sender.ino]
2026-08-04 Bump SF9->SF10 on both sender and dashboard (reinitRadio too) — +3dB sensitivity for 8.7km urban range
2026-08-04 Fix missed RX: remove interrupt guard (timing-safe), post-draw startReceive re-arm, skip draw if receivedFlag set, print readData errors
    [gridwatcher_dashboard2.ino]
2026-08-04 Fix LoRa SPI corruption: Move TFT init before radio.begin, add startReceive error logging
    [gridwatcher_dashboard2.ino]
2026-08-04 Add DIO1 pin polling fallback — bypasses ESP32-C6 GPIO interrupt failure; re-attach ISR on every watchdog re-arm
    [gridwatcher_dashboard2.ino]
2026-08-04 Diag: disable DIO2 RF switch on handheld (blocks RX on modules without external switch); add DIO1 pin state logging
2026-08-04 Set TX_POWER_DBM=9 for legal compliance with +5dBi 868MHz LoRa antenna
2026-08-04 Sender-hub OTA: LittleFS firmware store, handheld pulls from sender AP, bridge auto-updates from hub, sender reboots last
    [gridwatcher_dashboard2.ino, home_sender.ino]
2026-08-04 Fix sender syntax error, remove unused WebServer/ESPmDNS from handheld to free up ~100KB flash
    [gridwatcher_dashboard2.ino, home_sender.ino]
2026-08-04 Add Termux standalone capability to bridge script, including direct urllib HTTP, local cellinfo/battery parsing, and automated outage SMS alerts
2026-08-04 Replace non-ASCII em-dashes with standard hyphens in home_sender.ino to prevent Windows compilation encoding errors
    [home_sender.ino]
2026-08-04 Implement simulated outage trigger via Home Sender boot button and automatic phone SMS warning
2026-08-05 Update README.md with V1 vs V2 project roadmap (defining professional V2 custom PCB stack)
2026-08-07 Integrate ZMPT101B real AC voltage and frequency measurements on GPIO 2 with calibration web endpoint
2026-08-07 Add DC bias sanity check and P2P noise thresholding for ZMPT101B sensor
    [home_sender.ino]
2026-08-07 Update PIN_ZMPT to GPIO 6 to match physical wiring
2026-08-09 Integrate Direct GitHub HTTPS Auto-OTA self-flashing engine and ML weights into ESP32 Base Station
2026-08-09 Scrub Wi-Fi credentials and replace with placeholders
    [home_sender.ino]
2026-08-09 Implement secrets.h pattern with .gitignore protection for seamless local compilation and GitHub privacy
    [gridwatcher_dataset.csv, gridwatcher_dataset_phone.csv, telemetry.csv]
2026-08-10 Include voltage and frequency in handleStatus JSON endpoint and clean README.md formatting
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2026-08-10 Integrate ESP32 NVS Preferences flash persistence for Wi-Fi credentials across Auto-OTA updates
2026-08-10 Fix C++ Preferences.h include placement to resolve Arduino IDE compilation error
    [home_sender.ino]
2026-08-10 Auto-retrain ML Model v2 [21:15:06]
    [telemetry.csv]
2026-08-10 Auto-retrain ML Model v3 [21:48:09]
    [telemetry.csv]
2026-08-10 Upload compiled home_sender.bin firmware binary for GitHub HTTPS Auto-OTA self-flashing
    [telemetry.csv]
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2026-08-10 Fix NVS flash Wi-Fi credential saving logic and extend WPA2 handshake timeout to 15s
    [home_sender.ino]
2026-08-10 Add /stage-handheld endpoint: pull handheld.bin from GitHub on demand independently of ML version
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2026-08-10 Auto-retrain ML Model v4 [23:13:56]
    [telemetry.csv]
2026-08-11 Auto-retrain ML Model v5 [07:13:01]
    [telemetry.csv]
2026-08-11 Auto-retrain ML Model v6 [08:41:05]
    [telemetry.csv]
2026-08-11 Fix trainer: add ML_MODEL_VERSION to grid_model.h, add arduino-cli build step, auto stage-handheld after OTA
    [telemetry.csv]
2026-08-11 v6 FINAL: Orange Pi HTTP OTA + SCP deploy in trainer — no more HTTPS failures
    [home_sender.ino]
2026-08-11 Auto-retrain ML Model v7 [09:22:00]
    [telemetry.csv]
2026-08-11 v7: Added 5 rapid LED debug blinks on /trigger-ota + synchronized versioning & Orange Pi HTTP OTA
    [telemetry.csv]
2026-08-11 Auto-retrain ML Model v8 [09:34:03]
    [telemetry.csv]
2026-08-11 Auto-retrain ML Model v8 [09:38:30]
    [telemetry.csv]
2026-08-11 Fix trainer GUI: shell=True for arduino-cli to fix WinError 2 on Windows
2026-08-11 Auto-retrain ML Model v9 [09:46:16]
    [telemetry.csv]
2026-08-11 Auto-retrain ML Model v10 [09:49:53]
    [telemetry.csv]
2026-08-11 Auto-retrain ML Model v11 [09:52:08]
    [telemetry.csv]
2026-08-11 Auto-retrain ML Model v12 [10:34:15]
    [telemetry.csv]
2026-08-11 v12 COMPLETE: Fixed arduino-cli path search, compiled v12 binaries, uploaded to Pi and GitHub
    [telemetry.csv]
2026-08-11 Auto-retrain ML Model v13 [12:49:53]
    [telemetry.csv]
2026-08-11 FIXED: Pass explicit cwd=REPO_DIR to arduino-cli subprocess to prevent Windows path resolution errors
2026-08-11 FIXED: Use shell=True with quoted executable path for arduino-cli to fix WinError 2 on Windows
2026-08-11 Auto-retrain ML Model v14 [12:58:50]
    [telemetry.csv]
2026-08-11 FINAL FIX: Bulletproof path resolution and arduino-cli diagnostics
2026-08-11 FIX: installer downloads arduino-cli standalone, GUI checks tools/ folder first
2026-08-11 FIX: secrets.h optional via __has_include, NVS logic fixed, fresh binaries compiled
    [home_sender.ino]
2026-08-11 FIXED: Skip handheld compile in ML pipeline — handheld.ino never includes grid_model.h
2026-08-11 Auto-retrain ML Model v15 [15:06:17]
    [telemetry.csv]
2026-08-11 Auto-retrain ML Model v16 [15:15:45]
    [telemetry.csv]
2026-08-11 Auto-retrain ML Model v18 [18:16:28]
    [telemetry.csv]
2026-08-11 FIX: Resolved Handheld LoRa RX double-read FIFO bug to restore binary struct screen rendering
    [gridwatcher_dashboard2.ino]
2026-08-11 Added base_battery and phone_battery fields to GridPacket struct for full battery telemetry reporting
2026-08-11 v19: Staged v19 binaries with 12-byte binary struct for Home Assistant Auto-OTA test
2026-08-11 Auto-retrain ML Model v20 [20:53:59]
    [telemetry.csv]
2026-08-11 Auto-retrain ML Model v20 [20:54:29]
    [telemetry.csv]
2026-08-11 v20: Saved cadence fix, clean signal sentinels, 1Hz ticker, and 12-byte binary struct for tomorrow
    [home_sender.ino]
2026-08-12 Auto-retrain ML Model v21 [15:07:57]
    [telemetry.csv]
2026-08-12 Auto-retrain ML Model v22 [16:39:24]
    [telemetry.csv]
2026-08-12 Auto-retrain ML Model v23 [16:49:51]
    [telemetry.csv]
2026-08-12 Auto-retrain ML Model v24 [16:57:18]
    [telemetry.csv]
2026-08-12 Auto-retrain ML Model v25 [17:02:32]
    [telemetry.csv]
2026-08-12 Auto-retrain ML Model v26 [17:10:49]
    [telemetry.csv]
2026-08-12 Auto-retrain ML Model v27 [17:23:40]
    [telemetry.csv]
2026-08-12 Auto-retrain ML Model v28 [17:32:09]
    [telemetry.csv]
2026-08-12 CRITICAL AUDIT FIX: Staged and committed pure timestamp-based gridwatcher_ml_gui.py (merge_asof 10s, ddof=0 30s rolling std, 30s regression slope, 30s reverse target labeling)
2026-08-12 Auto-retrain ML Model v29 [17:36:39]
    [telemetry.csv]
2026-08-12 Auto-retrain ML Model v30 [17:51:29]
    [telemetry.csv]
2026-08-12 Auto-retrain ML Model v31 [18:24:12]
    [telemetry.csv]
2026-08-12 FIRMWARE AUTO-OTA FIX: Implemented complete HTTP/HTTPS download, Update.begin/write/end stream flashing, and restart flow in checkGitHubAutoOTA()
    [home_sender.ino]
2026-08-13 DOCUMENTATION REFINEMENT: Updated README.md with non-emoji architecture, shields badges, Mermaid data flow diagram, human story, and collapsible specs
2026-08-13 DOCUMENTATION REFINEMENT: Updated hook pricing to ~R1,500 and added prototype Bill of Materials ZAR table
2026-08-16 AUTO-OTA FIX: Scoped WiFiClient/WiFiClientSecure to function scope to keep TCP stream alive during Update.writeStream
    [home_sender.ino]
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2026-08-16 POWER: Boosted LoRa TX power to maximum +22 dBm (160mW) and added dynamic /lora-power tuning endpoint
2026-11-04 fix(bom): update JLCPCB verified LCSC C-codes for C1, C2, C19, R2, R4/R5
2026-11-04 fix(bom): correct J2 to C2963104 (Nano-SIM) and Q1/Q2 to C52895 (BSS138)
2026-11-04 fix(bom): update L1 to C915310 (10uH SMD inductor)
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2026-11-12 fix(bom): strip descriptive notes from URL columns for strict validator

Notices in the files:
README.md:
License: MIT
